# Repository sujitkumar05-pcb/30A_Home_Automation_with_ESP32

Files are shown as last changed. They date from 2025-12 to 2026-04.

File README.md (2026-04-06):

# 30A_Home_Automation_with_ESP32

## 1. Project Overview

30A Home Automation with ESP32 is a high-power IoT control system designed to safely switch electrical loads up to 30A. It uses the ESP32 for Wi-Fi–based remote control and automation. The complete schematic, PCB layout, and 3D design were developed in KiCad, with a strong focus on electrical isolation, proper track width, and safety for real-world applications.

-----

## 2. Key Learning Objectives

Understanding high-current (30A) PCB design and safety considerations

Practical experience with ESP32-based IoT hardware development

Schematic capture and multi-layer PCB layout using KiCad

Track width calculation, creepage & clearance implementation

Hardware testing, debugging, and design verification

Generating manufacturing (Gerber) and 3D output files

-----

## 3. Tools & Software Used
- **KiCad EDA**
  - Schematic Editor  
  - PCB Layout Editor  
  - 3D Viewer
 
 ---

## 4. Project Files
- Schematic design files (`.kicad_sch`)  
- PCB layout files (`.kicad_pcb`)  
- 3D render images  
- Manufacturing-ready Gerber files  

---

## 5. Block-Level Working Explanation

The system is powered by an AC mains supply, which is converted to a regulated DC voltage using a power supply module to safely operate the control circuitry. The ESP32 acts as the main controller, receiving user commands via Wi-Fi from a mobile or web application.

Based on these commands, the ESP32 drives an isolated switching stage (relay/contactor or solid-state device), ensuring safe separation between low-voltage control and high-current load circuits. The switching stage controls the connected 30A electrical load, turning it ON or OFF as required.

Protection components such as fuses, flyback diodes, and filtering circuits are included to enhance safety, reliability, and noise immunity. The system provides reliable remote control while maintaining electrical isolation and thermal safety.

## 6. Bill of Materials (BOM)
| Reference | Qty | Value / Part No. | Footprint | Datasheet / Notes |
| --- | --- | --- | --- | --- |
| C1 | 1 | 10 µF | C_0805_2012Metric | – |
| C2 | 1 | 22 µF | C_0805_2012Metric | – |
| D1, D4 | 2 | LED | LED_0805_2012Metric  | – |
| D2, D3 | 2 | 1N4148 | DO-35 (THT) | Nexperia |
| H1–H4 | 4 | Mounting Hole M2.5 | MountingHole_2.7 mm  | Excluded from BOM |
| J1 | 1 | 1×4 Pin Header | PinHeader_2.54 mm | – |
| J2 | 1 | 4-Pin Screw Terminal  | Phoenix MSTB 5.08 mm | – |
| J3 | 1 | 3-Pin Screw Terminal  | Phoenix MSTB 5.08 mm | – |
| K1 | 1 | RAYEX-L90AS Relay | Relay_SPST_THT | RAYEX |
| K2 | 1 | PR13-5V-450-1C Relay  | Relay THT | – |
| PS1 | 1 | HLK-PM01 AC–DC Module | Hi-Link_HLK-PMxx | Hi-Link |
| Q1, Q2 | 2 | S8050 Transistor | TO-92 | – |
| R1–R6 | 6 | 1 kΩ | R_0805_2012Metric | – |
| R7, R8 | 2 | 10 kΩ | R_0805_2012Metric | – |
| SW1, SW2  | 2 | Push Button Switch | 6 mm THT | – |
| U1 | 1 | ESP32-WROOM-32 | RF_Module | Espressif |
| U2, U3 | 2 | PC817 Optocoupler | DIP-4 | – |
| U4 | 1 | AMS1117-3.3 | TO-252-3 | – |

## 7. Images & Renders

- **Schematic**


- **PCB Layout**
 
 
 
- **3D View**



## 8. Disclaimer
This project is intended for educational and experimental purposes only. It involves high-voltage and high-current (up to 30A) circuits, which can be dangerous if handled improperly. The author is not responsible for any damage, injury, or loss resulting from the use, modification, or implementation of this design.
Users are advised to follow proper electrical safety standards, use appropriate protective components, and verify the design thoroughly before real-world deployment

---

## 9. Author
- **Name:** Er.SUJIT KUMAR
- **Toolchain:** KiCad EDA

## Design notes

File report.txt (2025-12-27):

Plotted to 'D:\Sujit PCB\All in one PCB project\my Self pcb\30A_Home_Automation_with_ESP32\gerber\30A_Home_Automation_with_ESP32-F_Cu.gbr'.
Plotted to 'D:\Sujit PCB\All in one PCB project\my Self pcb\30A_Home_Automation_with_ESP32\gerber\30A_Home_Automation_with_ESP32-B_Cu.gbr'.
Plotted to 'D:\Sujit PCB\All in one PCB project\my Self pcb\30A_Home_Automation_with_ESP32\gerber\30A_Home_Automation_with_ESP32-F_Paste.gbr'.
Plotted to 'D:\Sujit PCB\All in one PCB project\my Self pcb\30A_Home_Automation_with_ESP32\gerber\30A_Home_Automation_with_ESP32-B_Paste.gbr'.
Plotted to 'D:\Sujit PCB\All in one PCB project\my Self pcb\30A_Home_Automation_with_ESP32\gerber\30A_Home_Automation_with_ESP32-F_Silkscreen.gbr'.
Plotted to 'D:\Sujit PCB\All in one PCB project\my Self pcb\30A_Home_Automation_with_ESP32\gerber\30A_Home_Automation_with_ESP32-B_Silkscreen.gbr'.
Plotted to 'D:\Sujit PCB\All in one PCB project\my Self pcb\30A_Home_Automation_with_ESP32\gerber\30A_Home_Automation_with_ESP32-F_Mask.gbr'.
Plotted to 'D:\Sujit PCB\All in one PCB project\my Self pcb\30A_Home_Automation_with_ESP32\gerber\30A_Home_Automation_with_ESP32-B_Mask.gbr'.
Plotted to 'D:\Sujit PCB\All in one PCB project\my Self pcb\30A_Home_Automation_with_ESP32\gerber\30A_Home_Automation_with_ESP32-Edge_Cuts.gbr'.
Created Gerber job file 'D:\Sujit PCB\All in one PCB project\my Self pcb\30A_Home_Automation_with_ESP32\gerber\30A_Home_Automation_with_ESP32-job.gbrjob'.
Info: Done.
Info: Done.

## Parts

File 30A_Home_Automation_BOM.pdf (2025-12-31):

# 30A Home Automation with ESP32

## Bill of Materials (BOM)

Reference | Qty | Value / Part Number | Footprint | Notes / Datasheet
C1 | 1 | 10µF | 0805 | -
C2 | 1 | 22µF | 0805 | -
D1, D4 | 2 | LED | LED 0805 | Status LED
D2, D3 | 2 | 1N4148 | DO-35 | Signal diode
H1–H4 | 4 | Mounting Hole | M2.5 | Excluded from BOM
J1 | 1 | Conn 01x04 | PinHeader 2.54mm | -
J2 | 1 | Screw Terminal 01x04 | 5.08mm | -
J3 | 1 | Screw Terminal 01x03 | 5.08mm | -
K1 | 1 | RAYEX-L90AS | Relay THT | 30A Load Relay
K2 | 1 | PR13-5V-450-1C | Relay THT | -
PS1 | 1 | HLK-PM01 | AC-DC Module | 5V SMPS
Q1, Q2 | 2 | S8050 | TO-92 | NPN Transistor
R1–R6 | 6 | 1kΩ | 0805 | -
R7, R8 | 2 | 10kΩ | 0805 | -
SW1, SW2 | 2 | Push Button | 6mm THT | -
U1 | 1 | ESP32-WROOM-32 | RF Module | Main MCU
U2, U3 | 2 | PC817 | DIP-4 | Optocoupler
U4 | 1 | AMS1117-3.3 | TO-252 | 3.3V Regulator

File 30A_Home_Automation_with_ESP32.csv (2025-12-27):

Reference | Qty | Value | DNP | Exclude from BOM | Exclude from Board | Footprint | Datasheet
C1 | 1 | 10uF |  |  |  | Capacitor_SMD:C_0805_2012Metric | ~
C2 | 1 | 22uF |  |  |  | Capacitor_SMD:C_0805_2012Metric | ~
D1,D4 | 2 | LED |  |  |  | LED_SMD:LED_0805_2012Metric | ~
D2,D3 | 2 | 1N4148 |  |  |  | Diode_THT:D_DO-35_SOD27_P7.62mm_Horizontal | https://assets.nexperia.com/documents/data-sheet/1N4148_1N4448.pdf
H1,H2,H3,H4 | 4 | MountingHole_Pad |  | Excluded from BOM |  | MountingHole:MountingHole_2.7mm_M2.5_Pad_Via | ~
J1 | 1 | Conn_01x04_Pin |  |  |  | Connector_PinHeader_2.54mm:PinHeader_1x04_P2.54mm_Vertical | ~
J2 | 1 | Screw_Terminal_01x04 |  |  |  | Connector_Phoenix_MSTB:PhoenixContact_MSTBVA_2,5_4-G-5,08_1x04_P5.08mm_Vertical | ~
J3 | 1 | Screw_Terminal_01x03 |  |  |  | Connector_Phoenix_MSTB:PhoenixContact_MSTBVA_2,5_3-G-5,08_1x03_P5.08mm_Vertical | ~
K1 | 1 | RAYEX-L90AS |  |  |  | Relay_THT:Relay_SPST_RAYEX-L90AS | https://a3.sofastcdn.com/attachment/7jioKBjnRiiSrjrjknRiwS77gwbf3zmp/L90-SERIES.pdf
K2 | 1 | PR13-5V-450-1C |  |  |  | PR13-5V-450-1C:RELAY_PR13-5V-450-1C
PS1 | 1 | HLK-PM01 |  |  |  | Converter_ACDC:Converter_ACDC_Hi-Link_HLK-PMxx | https://h.hlktech.com/download/ACDC%E7%94%B5%E6%BA%90%E6%A8%A1%E5%9D%973W%E7%B3%BB%E5%88%97/1/%E6%B5%B7%E5%87%8C%E7%A7%913W%E7%B3%BB%E5%88%97%E7%94%B5%E6%BA%9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
Q1,Q2 | 2 | S8050 |  |  |  | Package_TO_SOT_THT:TO-92_Inline | http://www.unisonic.com.tw/datasheet/S8050.pdf
R1,R2,R3,R4,R5,R6 | 6 | 1K |  |  |  | Resistor_SMD:R_0805_2012Metric | ~
R7,R8 | 2 | 10K |  |  |  | Resistor_SMD:R_0805_2012Metric | ~
SW1,SW2 | 2 | SW_Push |  |  |  | Button_Switch_THT:SW_PUSH_6mm | ~
U1 | 1 | ESP32-WROOM-32 |  |  |  | RF_Module:ESP32-WROOM-32 | https://www.espressif.com/sites/default/files/documentation/esp32-wroom-32_datasheet_en.pdf
U2,U3 | 2 | PC817 |  |  |  | Package_DIP:DIP-4_W7.62mm | http://www.soselectronic.cz/a_info/resource/d/pc817.pdf
U4 | 1 | AMS1117CD-3.3 |  |  |  | Package_TO_SOT_SMD:TO-252-3_TabPin2 | http://www.advanced-monolithic.com/pdf/ds1117.pdf

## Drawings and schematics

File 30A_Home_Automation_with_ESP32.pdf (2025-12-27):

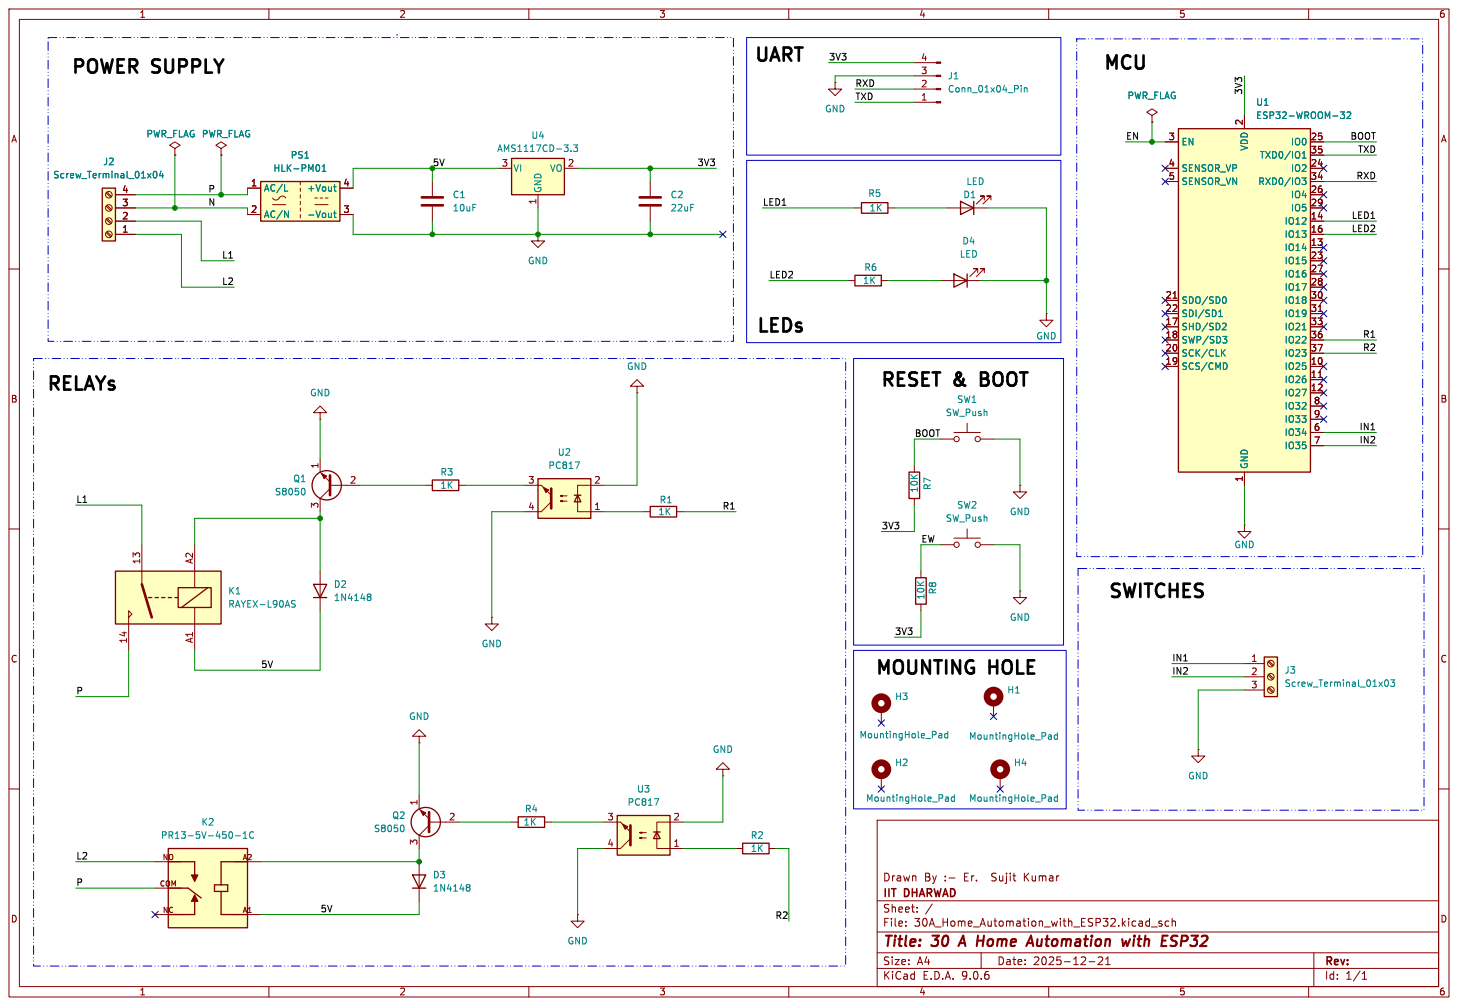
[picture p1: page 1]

File: 30A_Home_Automation_with_ESP32.kicad_sch Sheet: /
Id: 1/1 Title: 30 A Home Automation with ESP32

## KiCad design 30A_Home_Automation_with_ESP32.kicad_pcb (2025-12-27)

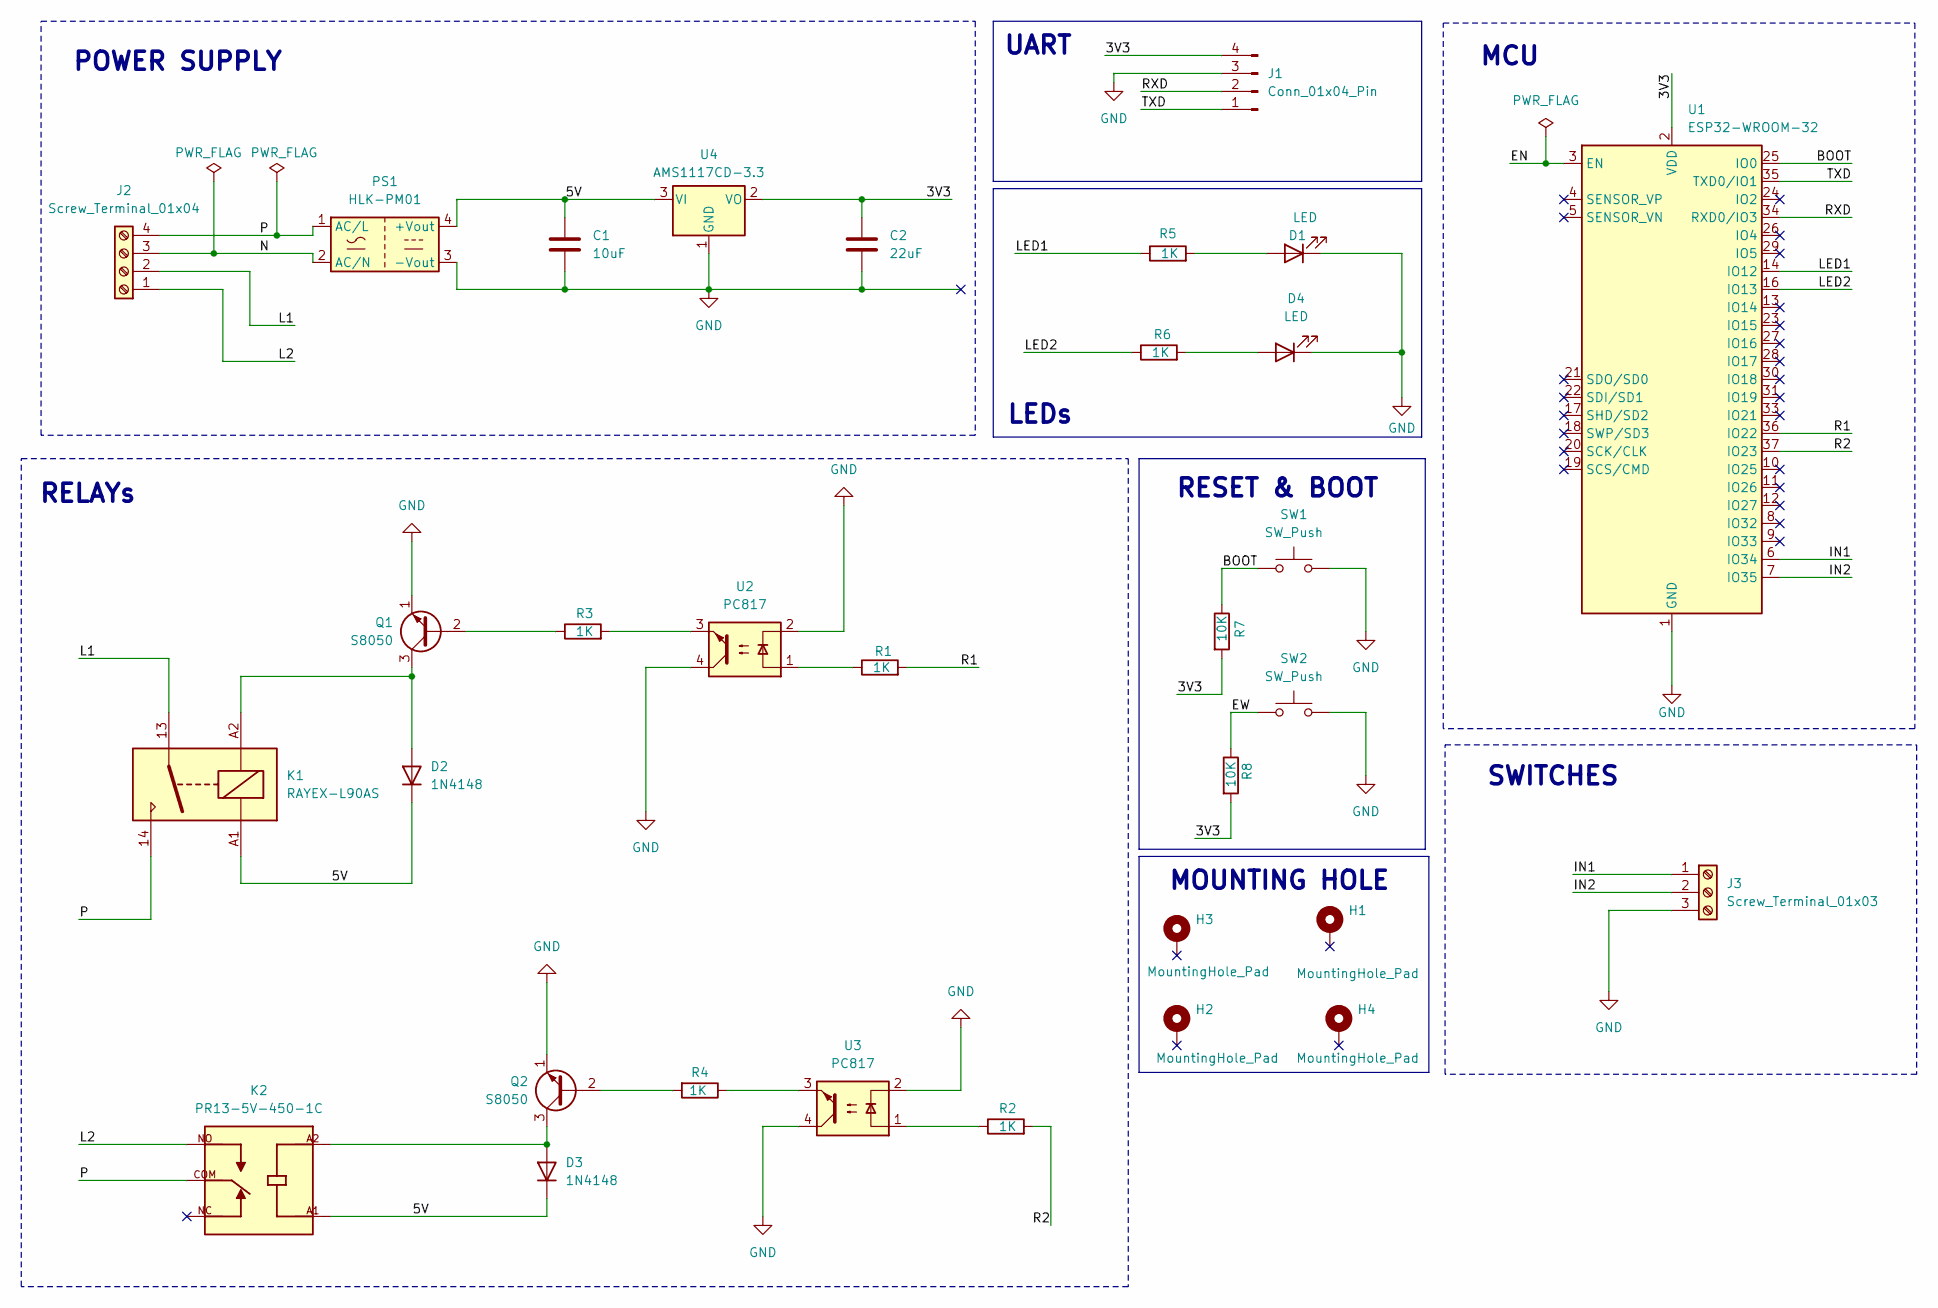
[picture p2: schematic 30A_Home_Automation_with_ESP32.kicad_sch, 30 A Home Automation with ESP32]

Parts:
C1: 10uF; C_0805_2012Metric
C2: 22uF; C_0805_2012Metric
D1, D4: LED; LED_0805_2012Metric
D2, D3: 1N4148; D_DO-35_SOD27_P7.62mm_Horizontal
H1, H2, H3, H4: MountingHole_Pad; MountingHole_2.7mm_M2.5_Pad_Via
J1: Conn_01x04_Pin; PinHeader_1x04_P2.54mm_Vertical
J2: Screw_Terminal_01x04; PhoenixContact_MSTBVA_2,5_4-G-5,08_1x04_P5.08mm_Vertical
J3: Screw_Terminal_01x03; PhoenixContact_MSTBVA_2,5_3-G-5,08_1x03_P5.08mm_Vertical
K1: RAYEX-L90AS; Relay_SPST_RAYEX-L90AS
K2: PR13-5V-450-1C; RELAY_PR13-5V-450-1C; PARTREV 1.0
PS1: HLK-PM01; Converter_ACDC_Hi-Link_HLK-PMxx
Q1, Q2: S8050; TO-92_Inline
R1, R2, R3, R4, R5, R6: 1K; R_0805_2012Metric
R7, R8: 10K; R_0805_2012Metric
SW1, SW2: SW_Push; SW_PUSH_6mm
U1: ESP32-WROOM-32
U2, U3: PC817; DIP-4_W7.62mm
U4: AMS1117CD-3.3; TO-252-3_TabPin2

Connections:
/3V3: C2.1, J1.4, R7.2, R8.2, U1.2 (VDD), U4.2 (VO)
/5V: C1.1, D2.1 (K), D3.1 (K), K1.A1, K2.A1, PS1.4 (+Vout), U4.3 (VI)
/BOOT: R7.1, SW1.1, U1.25 (IO0)
/EN: U1.3 (EN)
/EW: R8.1, SW2.1
/IN1: J3.1, U1.6 (IO34)
/IN2: J3.2, U1.7 (IO35)
/L1: J2.2, K1.13
/L2: J2.1, K2.NO
/LED1: R5.1, U1.14 (IO12)
/LED2: R6.1, U1.16 (IO13)
/N: J2.3, PS1.2 (AC/N)
/P: J2.4, K1.14, K2.COM, PS1.1 (AC/L)
/R1: R1.2, U1.36 (IO22)
/R2: R2.2, U1.37 (IO23)
/RXD: J1.2, U1.34 (RXD0/IO3)
/TXD: J1.1, U1.35 (TXD0/IO1)
GND: C1.2, C2.2, D1.1 (K), D4.1 (K), J1.3, J3.3, PS1.3 (-Vout), Q1.1 (E), Q2.1 (E), SW1.2, SW2.2, U1.1 (GND), U1.15 (GND), U1.38 (GND), U1.39 (GND), U2.2, U2.4, U3.2, U3.4, U4.1 (GND)
unnamed: D1.2 (A), R5.2
unnamed: D2.2 (A), K1.A2, Q1.3 (C)
unnamed: D3.2 (A), K2.A2, Q2.3 (C)
unnamed: D4.2 (A), R6.2
unnamed: Q1.2 (B), R3.1
unnamed: Q2.2 (B), R4.2
unnamed: R1.1, U2.1
unnamed: R2.1, U3.1
unnamed: R3.2, U2.3
unnamed: R4.1, U3.3

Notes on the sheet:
SWITCHES
LEDs
POWER SUPPLY
MOUNTING HOLE
RELAYs
MCU
UART
RESET & BOOT

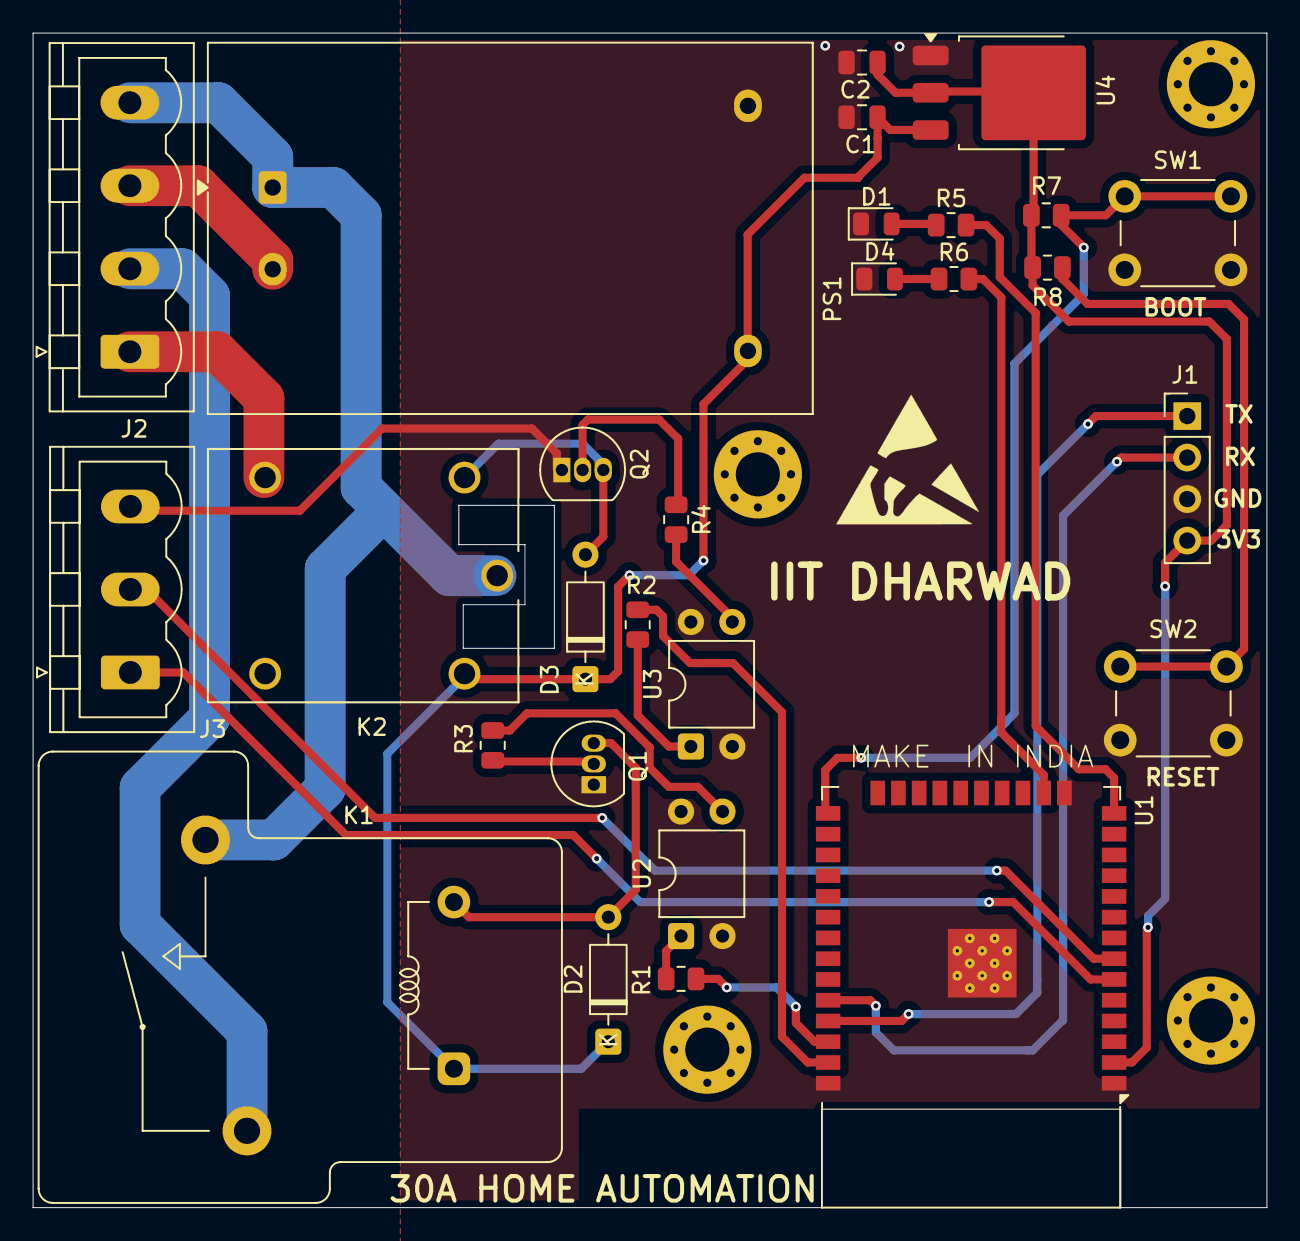
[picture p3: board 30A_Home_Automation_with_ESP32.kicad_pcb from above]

Board: 2 copper layers, 75.5 x 71.9 mm, 32 parts (0 on the bottom side), 27 nets.
